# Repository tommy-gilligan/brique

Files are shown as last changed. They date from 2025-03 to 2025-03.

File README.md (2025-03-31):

# RP235x Nokia 3310 Adapter Board

This started as a cute "what if?":

> What if I could type out messages on my smart phone by using tactile buttons like I used to have on my phone back in high school?

Because the board would need to fit into the chassis of a Nokia 3310 and because there are existing doodads that would be sitting alongside the board anyways, scope has crept to include connecting to these other thingamajigs.

3D render of front of adapter board
3D render of back of adapter board

## Setting up web environment

## Setting up rp environment

## Setting up board
### Ordering Board
### Disassemble 3310
### Install Hardware Test Program
### Reassemble 3310
### Manual Test
### Install Custom Software

- RTC
- supercapacitor

### TODO
#### Sooner
##### Hardware
- dress up repo
- Come up with better name
- add back supercap rtc
- double check power regulation
- add jlcpcb part numbers, 3d models

##### Software
- create example that plays RTTTL (and writes it to screen)
- Snake
- USB text entry
- use text_input for inputing secret for TOTP (drives the need for inputting numeric digits easily and RTC)

#### Later
- optional pico-w for wifi/bluetooth (using a module avoids need for recertification?)
    - looks like RP will release such a module (RM2) so go ahead with designing with that in mind
- detect battery type to refuse NiMH
- battery gauge
- flex pcb for keypad?
- LTE modem?
- e-ink display?
- power button used for BOOT/RUN?

https://serdisplib.sourceforge.net/ser/pcd8544.html

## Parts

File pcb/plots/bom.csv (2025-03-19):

Comment | Designator | Footprint | JLCPCB Part #
SW_Push | SW1 | power switch | C128539
10u | C23,C25,C19 | C_0805_2012Metric | C17024
ABM8-272-T3 | Y1 | Crystal_SMD_3225-4Pin_3.2x2.5mm | C20625731
27 | R7,R8 | R_0402_1005Metric | C25100
1k | R2 | R_0402_1005Metric | C25543
1K | R41 | R_0402_1005Metric | C25543
NCP1117-3.3_SOT223 | U2 | SOT-223-3_TabPin2 | C26537
D | D1 | D_0402_1005Metric | C2837790
RV-3028-C7_32.768kHz_1ppm_TA_QC | Y2 | MicroCrystal_RV3028C7 | C3019759
4.7u | C9,C6,C7,C10 | C_0402_1005Metric | C368809
BC847 | Q2,Q7,Q5,Q1,Q9 | SOT-23 | C391423
3.3u | L1 | L_pol_2016 | C42411119
RP2350_80QFN | U5 | RP2350-QFN-80-1EP_10x10_P0.4mm_EP3.4x3.4mm_ThermalVias | C42415655
10k | R35,R34,R38,R1,R36 | R_0402_1005Metric | C60490
100k | R39 | R_0402_1005Metric | C60491
100n | C12,C18,C11,C16,C5,C14,C2,C21,C17,C24,C13,C20,C15,C8 | C_0402_1005Metric | C77020
33 | R3 | R_0402_1005Metric | C852729
15p | C4,C3 | C_0402_1005Metric | C86285
W25Q128JVS | U1 | SOIC-8_5.23x5.23mm_P1.27mm | C97521
4.7uH | L2 | L_Neosid_MicroCoil_Ms36-L | C48427
LED | D2,D3,D4,D7,D9,D5,D6,D8 | LED_REVERSE | C3646932
100nF | C26,C29 | C_0805_2012Metric | C1711
3k | R14,R44,R54,R52,R45,R58,R51,R46,R50,R53,R47,R56,R57,R55,R59,R49,R48 | R_0402_1005Metric | C137872
22uF | C27,C30,C35,C1,C28 | C_0805_2012Metric | C602037
MAX16054 | U4 | SOT-23-6 | C79401
220 | R10,R9,R4,R6,R5,R13,R11,R12 | R_0402_1005Metric | C137872
SW_Push | SW2 | SW_SPST_PTS810 | C221895
100nF | C79 | C_0402_1005Metric | C77020
USB_B_Micro | J5 | USB_Micro-B_Molex_47346-0001 | C132560
120R | R37 | R_0402_1005Metric | C114758
SS34 | D12 | D_SMA | C8678
TP5400 | U3 | SOIC-8_3.9x4.9mm_P1.27mm | C2891434

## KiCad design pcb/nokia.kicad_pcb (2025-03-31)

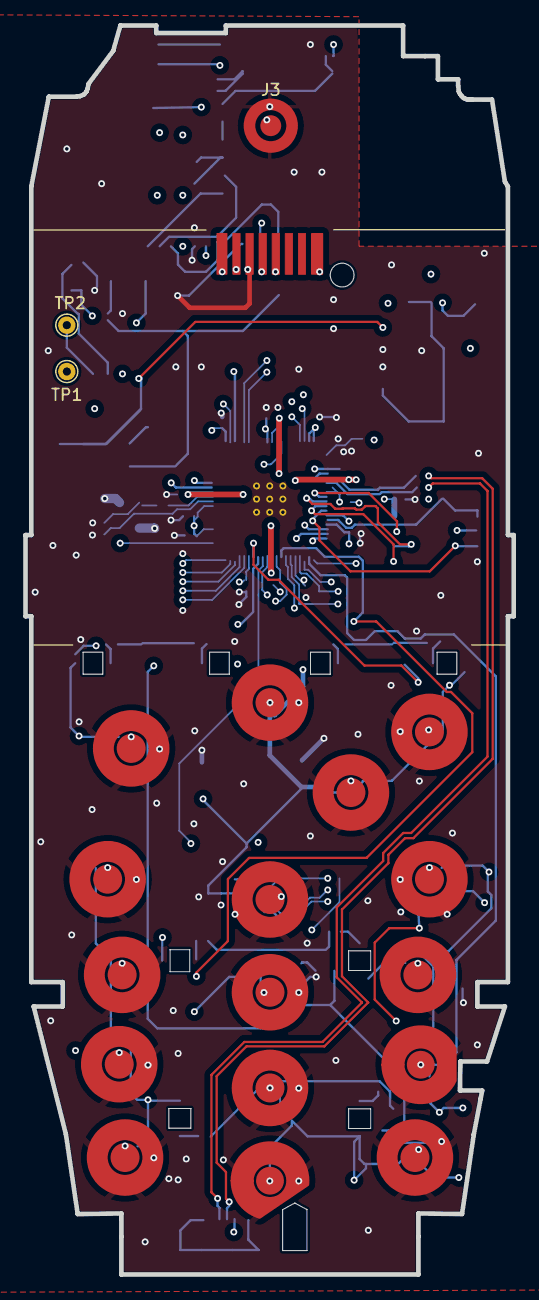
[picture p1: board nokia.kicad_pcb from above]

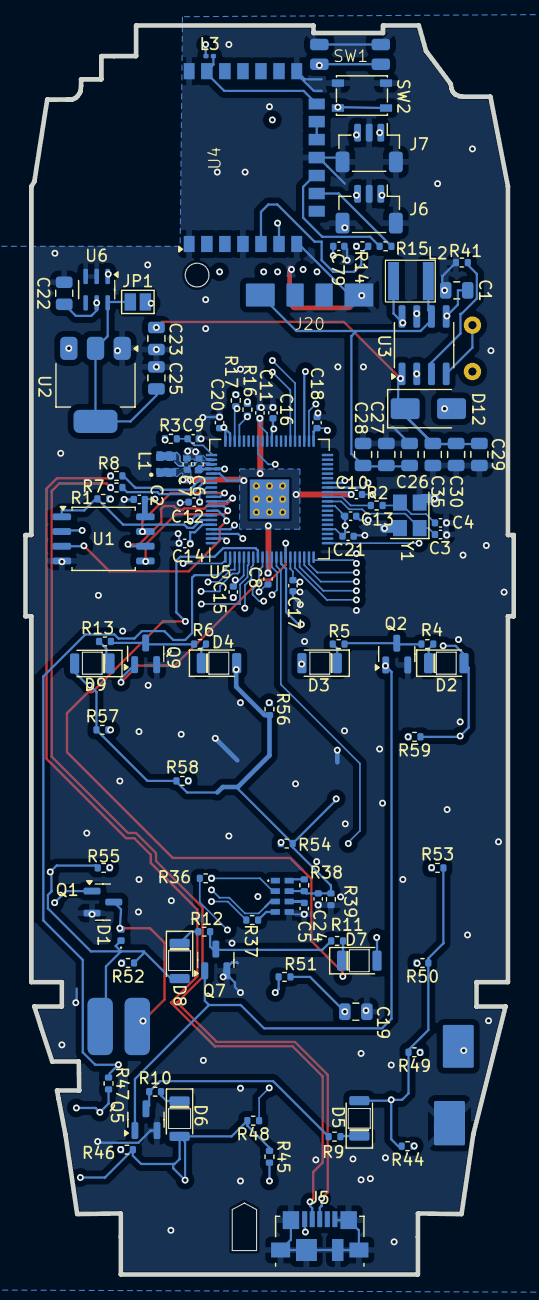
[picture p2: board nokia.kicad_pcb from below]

Board: 4 copper layers, 42.1 x 107.7 mm, 125 parts (105 on the bottom side), 81 nets.

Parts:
C1, C27, C28, C30, C35: 22uF; C_0805_2012Metric
C2, C5, C8, C11, C12, C13, C14, C15, C16, C17, C18, C20, C21, C24: 100n; C_0402_1005Metric
C3, C4: 15p; C_0402_1005Metric
C6, C7, C9, C10: 4.7u; C_0402_1005Metric
C19, C22, C23, C25: 10u; C_0805_2012Metric
C26, C29: 100nF; C_0805_2012Metric
C79: 100nF; C_0402_1005Metric
D1: D; D_0402_1005Metric
D2, D3, D4, D5, D6, D7, D8, D9: LED; LED_REVERSE
D12: SS34; D_SMA
J1: Conn_01x07; screen
J3: Conn_01x02_Pin; PinHeader_1x02_P1.00mm_Vertical_SMD_Pin1Left
J5: USB_B_Micro; USB_Micro-B_Molex_47346-0001
J6, J7: SM03B-SRSS-TB; JST_SH_BM03B-SRSS-TB_1x03-1MP_P1.00mm_Vertical
J20: Battery Connection Pads; battery
JP1: Jumper_2_Open; SolderJumper-2_P1.3mm_Open_Pad1.0x1.5mm
KP0, KP1, KP2, KP4, KP5, KP6, KP7, KP8, KP9: Jumper_2_Open; thick-pad
KP3: 3; thick-pad
KP#1: Jumper_2_Open; thick-pad
KP*1: Jumper_2_Open; thick-pad
KPC1: C; thick-pad
KPDOWN1: Jumper_2_Open; thick-pad
KPSELECT1: Jumper_2_Open; thick-pad
KPUP1: Jumper_2_Open; thick-pad
L1: 3.3u; L_pol_2016
L2: 4.7uH; L_Neosid_MicroCoil_Ms36-L
L3: BLM18EG471SN1D; L_0201_0603Metric
LS2: Buzzer; buzzer
M1: Vibration; vibrator
Q1, Q2, Q5, Q7, Q9: BC847; SOT-23
R1, R15, R16, R17, R36, R38: 10k; R_0402_1005Metric
R2: 1k; R_0402_1005Metric
R3: 33; R_0402_1005Metric
R4, R5, R6, R9, R10, R11, R12, R13: 220; R_0402_1005Metric
R7, R8: 27; R_0402_1005Metric
R14: 470; R_0402_1005Metric
R37: 120R; R_0402_1005Metric
R39: 100k; R_0402_1005Metric
R41: 1K; R_0402_1005Metric
R44, R45, R46, R47, R48, R49, R50, R51, R52, R53, R54, R55, R56, R57, R58, R59: 3k; R_0402_1005Metric
SW1: SW_Push; power switch
SW2: SW_Push; SW_SPST_PTS810
TP1, TP2: TestPoint; TestPoint_THTPad_D1.5mm_Drill0.7mm
U1: W25Q128JVS; SOIC-8_5.23x5.23mm_P1.27mm
U2: NCP1117-3.3_SOT223; SOT-223-3_TabPin2
U3: TP5400; SOIC-8_3.9x4.9mm_P1.27mm
U4: RM2
U5: RP2350_80QFN; RP2350-QFN-80-1EP_10x10_P0.4mm_EP3.4x3.4mm_ThermalVias
U6: MAX16054; SOT-23-6
Y1: ABM8-272-T3; Crystal_SMD_3225-4Pin_3.2x2.5mm
Y2: RV-3028-C7_32.768kHz_1ppm_TA_QC; MicroCrystal_RV3028C7

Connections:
+1V1: C7.1, C8.1, C10.1, C11.1, L1.1, U5.10 (DVDD), U5.32 (DVDD), U5.51 (DVDD), U5.65 (VREG_FB)
+3V3: C2.1, C6.1, C12.1, C13.1, C14.1, C15.1, C16.1, C17.1, C18.1, C19.1, C20.1, C21.1, C22.1, C24.1, D1.1 (K), D2.2 (A), D3.2 (A), D4.2 (A), D5.2 (A), D6.2 (A), D7.2 (A), D8.2 (A), D9.2 (A), J1.1, JP1.2 (B), L3.1, M1.1 (+), R3.1, R16.2, R17.1, R36.1, R38.1, R39.1, R44.2, R45.2, R46.2, R47.2, R48.2, R49.2, R50.1, R51.1, R52.1, R53.2, R54.2, R55.1, R56.2, R57.1, R58.1, R59.1, U1.8 (VCC), U5.5 (IOVDD), U5.15 (IOVDD), U5.24 (IOVDD), U5.29 (IOVDD), U5.41 (IOVDD), U5.50 (IOVDD), U5.59 (ADC_AVDD), U5.60 (IOVDD), U5.64 (VREG_VIN), U5.68 (USB_OTP_VDD), U5.69 (QSPI_IOVDD), U5.76 (IOVDD), U6.5 (OUT), Y2.7 (VDD)
+5V: C23.1, C29.2, C30.2, C35.2, D12.1 (K), U2.3 (VI), U3.1 (VOUT)
+BATT: C26.1, C27.1, C28.1, J20.1, L2.2, U3.6 (BAT)
-BATT: C1.2, C2.2, C3.2, C4.2, C5.2, C6.2, C7.2, C8.2, C9.2, C10.2, C11.2, C12.2, C13.2, C14.2, C15.2, C16.2, C17.2, C18.2, C19.2, C20.2, C21.2, C22.2, C23.2, C24.2, C25.2, C26.2, C27.2, C28.2, C29.1, C30.1, C35.1, C79.1, J1.6, J3.2, J5.5 (GND), J5.6 (Shield), J6.2, J6.MP (MountPin), J7.2, J7.MP (MountPin), J20.4, KP0.1 (A), KP1.1 (A), KP2.1 (A), KP3.1 (A), KP4.1 (A), KP5.1 (A), KP6.1 (A), KP7.1 (A), KP8.1 (A), KP9.1 (A), KP#1.1 (A), KP*1.1 (A), KPC1.1 (A), KPDOWN1.1 (A), KPSELECT1.1 (A), KPUP1.1 (A), LS2.2, Q1.2 (E), Q2.2 (E), Q5.2 (E), Q7.2 (E), Q9.2 (E), R39.2, R41.1, SW1.1, SW2.1, U1.4 (GND), U2.1 (GND), U3.7 (GND), U4.A1 (A1_GND), U4.A4 (A4_GND), U4.A7 (A7_GND), U4.B4 (B4_GND), U4.C1 (C1_GND), U4.C7 (C7_GND), U5.62 (VREG_PGND), U5.81 (GND), U6.2 (GND), U6.3 (CLEAR), Y1.2, Y1.4, Y2.5 (VSS)
/VREG_AVDD: C9.1, R3.2, U5.61 (VREG_AVDD)
/VREG_LX: L1.2, U5.63 (VREG_LX)
EVI: R38.2, Y2.8 (EVI)
GPIO0: J7.3, U5.77 (GPIO0)
GPIO1: J7.1, U5.78 (GPIO1)
GPIO2: Q1.1 (B), U5.79 (GPIO2)
GPIO4: KP#1.2 (B), R46.1, U5.1 (GPIO4)
GPIO5: KP9.2 (B), R47.1, U5.2 (GPIO5)
GPIO6: KP6.2 (B), R52.2, U5.3 (GPIO6)
GPIO7: KP3.2 (B), R55.2, U5.4 (GPIO7)
GPIO8: KPDOWN1.2 (B), R58.2, U5.6 (GPIO8)
GPIO9: KPUP1.2 (B), R57.2, U5.7 (GPIO9)
GPIO10: KP0.2 (B), R45.1, U5.8 (GPIO10)
GPIO11: KP8.2 (B), R48.1, U5.9 (GPIO11)
GPIO12: KPSELECT1.2 (B), R56.1, U5.11 (GPIO12)
GPIO13: KP2.2 (B), R54.1, U5.12 (GPIO13)
GPIO14: KP5.2 (B), R51.2, U5.13 (GPIO14)
GPIO15: Q2.1 (B), Q5.1 (B), Q7.1 (B), Q9.1 (B), U5.14 (GPIO15)
GPIO16: KPC1.2 (B), R59.2, U5.16 (GPIO16)
GPIO17: KP1.2 (B), R53.1, U5.17 (GPIO17)
GPIO18: KP4.2 (B), R50.2, U5.18 (GPIO18)
GPIO19: KP7.2 (B), R49.1, U5.19 (GPIO19)
GPIO20: KP*1.2 (B), R44.1, U5.20 (GPIO20)
GPIO21: LS2.1, U5.21 (GPIO21)
GPIO33: J1.8, U5.42 (GPIO33)
GPIO34: J3.1, U5.43 (GPIO34)
GPIO36: J1.4, U5.45 (GPIO36)
GPIO37: J1.5, U5.46 (GPIO37)
unnamed: C4.1, R2.2, Y1.3
unnamed: D1.2 (A), M1.2 (-), Q1.3 (C)
unnamed: D2.1 (K), R4.2
unnamed: D3.1 (K), R5.2
unnamed: D4.1 (K), R6.2
unnamed: D5.1 (K), R9.2
unnamed: D6.1 (K), R10.2
unnamed: D7.1 (K), R11.2
unnamed: D8.1 (K), R12.2
unnamed: D9.1 (K), R13.2
unnamed: D12.2 (A), L2.1, U3.8 (LX)
unnamed: C79.2, J1.7
unnamed: C25.1, JP1.1 (A), U2.2 (VO), U6.6 (V_{CC})
unnamed: Q2.3 (C), R4.1, R5.1
unnamed: Q5.3 (C), R9.1, R10.1
unnamed: Q7.3 (C), R11.1, R12.1
unnamed: Q9.3 (C), R6.1, R13.1
unnamed: R1.2, SW2.2
unnamed: TP1.1, U3.2 (CHRG)
unnamed: R41.2, U3.3 (PROG)
unnamed: TP2.1, U3.4 (STDBY)
unnamed: R14.1, U4.A6 (A6_DO)
unnamed: R15.1, U4.B3 (B3_IRQ)
unnamed: L3.2, U4.B7 (B7_VDDIO), U4.C2 (C2_VDDBAT)
unnamed: R8.2, U5.66 (USB_DM)
unnamed: R7.2, U5.67 (USB_DP)
unnamed: SW1.2, U6.1 (IN)
unnamed: R37.1, Y2.4 (SDA)
unnamed: C5.1, Y2.6 (VBACKUP)
QSPI_SCLK: U1.6 (CLK), U5.71 (QSPI_SCLK)
QSPI_SD0: U1.5 (DI(IO0)), U5.72 (QSPI_SD0)
QSPI_SD1: U1.2 (DO(IO1)), U5.74 (QSPI_SD1)
QSPI_SD2: U1.3 (IO2), U5.73 (QSPI_SD2)
QSPI_SD3: U1.7 (IO3), U5.70 (QSPI_SD3)
QSPI_SS: R1.1, U1.1 (~CS), U5.75 (QSPI_SS)
RM2_CS: R15.2, U4.B2 (B2_CS)
RM2_DIO: R14.2, U4.A5 (A5_DI)
RM2_POWER: U4.B5 (B5_WLON), U4.B6 (B6_BTON)
RTC_SCL: R17.2, U5.58 (GPIO47_ADC7), Y2.3 (SCL)
RTC_SDA: R16.1, R37.2, U5.57 (GPIO46_ADC6)
SWCLK: J6.1, U5.33 (SWCLK)
SWD: J6.3, U5.34 (SWD)
USB_D+: J5.3 (D+), R7.1
USB_D-: J5.2 (D-), R8.1
VBUS: C1.1, J5.1 (VBUS), U3.5 (VCC)
XIN: C3.1, U5.30 (XIN), Y1.1
XOUT: R2.1, U5.31 (XOUT)
~INT: R36.2, U5.53 (GPIO42_ADC2), Y2.2 (~INT)

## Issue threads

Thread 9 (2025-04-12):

Institute changelog and force branched flow for issues

tommy-gilligan, 2025-04-12:

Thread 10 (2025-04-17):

Improve battery monitoring

tommy-gilligan, 2025-04-17:
- Add battery gauge
- Detect NiMH/LiPo to prevent using NiMH.  Could use ADC
- Use charge/standby pins from charging IC

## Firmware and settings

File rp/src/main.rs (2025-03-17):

#![no_std]
#![no_main]

#[unsafe(link_section = ".start_block")]
#[used]
pub static IMAGE_DEF: ImageDef = ImageDef::secure_exe();

// Program metadata for `picotool info`.
// This isn't needed, but it's recomended to have these minimal entries.
#[unsafe(link_section = ".bi_entries")]
#[used]
pub static PICOTOOL_ENTRIES: [embassy_rp::binary_info::EntryAddr; 6] = [
    embassy_rp::binary_info::rp_program_name!(c"rp235x-nokia-3310"),
    // in repo root: find pcb -type f \( -exec sha1sum "$PWD"/{} \; \) | awk '{print $1}' | sort | sha1sum | cut -b-10
    embassy_rp::binary_info::rp_pico_board!(c"rp235x-nokia-3310-5da11fc30e"),
    embassy_rp::binary_info::rp_program_description!(
        c"This example tests the RP Pico on board LED, connected to gpio 25"
    ),
    embassy_rp::binary_info::rp_cargo_version!(),
    embassy_rp::binary_info::rp_program_build_attribute!(),
    embassy_rp::binary_info::rp_program_url!(
        c"https://github.com/tommy-gilligan/rp235x-nokia-3310"
    ),
];

mod rtc;
mod button;
mod device;
mod usb;

use assign_resources::assign_resources;
use core::cell::RefCell;
use defmt::unwrap;
use defmt_rtt as _;
use embassy_executor::{Executor, Spawner};
use embassy_rp::{
    bind_interrupts,
    block::ImageDef,
    multicore::{Stack, spawn_core1},
    peripherals,
    peripherals::USB,
    spi,
    spi::Spi,
    usb::InterruptHandler,
};
use embassy_sync::blocking_mutex::Mutex;
use panic_probe as _;
use static_cell::StaticCell;

assign_resources! {
    usbs: Usbs{
        usb: USB,
    }
}

bind_interrupts!(struct Irqs {
    USBCTRL_IRQ => InterruptHandler<USB>;
});

static mut CORE1_STACK: Stack<4096> = Stack::new();
static EXECUTOR1: StaticCell<Executor> = StaticCell::new();

#[embassy_executor::main]
async fn main(_spawner: Spawner) {
    let p = embassy_rp::init(Default::default());
    let r = split_resources!(p);
    spawn_core1(
        p.CORE1,
        unsafe { &mut *core::ptr::addr_of_mut!(CORE1_STACK) },
        move || {
            let executor1 = EXECUTOR1.init(Executor::new());
            executor1.run(|spawner| unwrap!(spawner.spawn(usb::big_usb_task(spawner, r.usbs))));
        },
    );
    let _clock = rtc::Clock::new(p.I2C1, p.PIN_46, p.PIN_47);

    let mut display_config = spi::Config::default();
    display_config.frequency = 4_000_000;

    main_menu::main_menu(
        device::Device::new(
            p.PIN_2,
            p.PIN_4,
            p.PIN_5,
            p.PIN_6,
            p.PIN_7,
            p.PIN_8,
            p.PIN_9,
            p.PIN_10,
            p.PIN_11,
            p.PIN_12,
            p.PIN_13,
            p.PIN_14,
            p.PIN_15,
            p.PIN_16,
            p.PIN_17,
            p.PIN_18,
            p.PIN_19,
            p.PIN_20,
            p.PIN_21,
            p.PIN_33,
            p.PIN_36,
            p.PIN_37,
            p.PWM_SLICE2,
            &Mutex::new(
                RefCell::new(
                    Spi::new_blocking(
                        p.SPI0,
                        p.PIN_38,
                        p.PIN_39,
                        p.PIN_32,
                        display_config,
                    )
                )
            ),
        ).unwrap(),
        button::Button::new(p.PIN_28),
        crate::device::CdcSend,
        crate::device::Handler
    ).await;
}

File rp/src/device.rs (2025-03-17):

use core::cell::RefCell;
use embassy_rp::pwm::PwmError;
use embassy_rp::peripherals::{
    PIN_2, PIN_4, PIN_5, PIN_6, PIN_7, PIN_8, PIN_9, PIN_10, PIN_11, PIN_12, PIN_13, PIN_14,
    PIN_15, PIN_16, PIN_17, PIN_18, PIN_19, PIN_20, PIN_21, PIN_33, PIN_36, PIN_37, PWM_SLICE2,
    SPI0,
};
use embassy_sync::blocking_mutex::raw::NoopRawMutex;
use embedded_graphics_core::{
    Pixel,
    pixelcolor::BinaryColor,
    prelude::{Dimensions, DrawTarget},
    primitives::Rectangle,
};
mod backlight;
mod buzzer;
mod display;
mod keypad;
mod vibration_motor;

pub struct Device<'a> {
    keypad: keypad::ContactKeypad<'a>,
    backlight: backlight::Light<'a>,
    vibration_motor: vibration_motor::Motor<'a>,
    buzzer: buzzer::Beeper<'a>,
    display: display::Display<'a>,
}

unsafe impl Send for Device<'_> {}

impl<'a> Device<'a> {
    #[allow(clippy::too_many_arguments)]
    pub fn new(
        pin_2: PIN_2,
        pin_4: PIN_4,
        pin_5: PIN_5,
        pin_6: PIN_6,
        pin_7: PIN_7,
        pin_8: PIN_8,
        pin_9: PIN_9,
        pin_10: PIN_10,
        pin_11: PIN_11,
        pin_12: PIN_12,
        pin_13: PIN_13,
        pin_14: PIN_14,
        pin_15: PIN_15,
        pin_16: PIN_16,
        pin_17: PIN_17,
        pin_18: PIN_18,
        pin_19: PIN_19,
        pin_20: PIN_20,
        pin_21: PIN_21,
        pin_33: PIN_33,
        pin_36: PIN_36,
        pin_37: PIN_37,
        pwm_slice2: PWM_SLICE2,
        spi_bus: &'a embassy_sync::blocking_mutex::Mutex<
            NoopRawMutex,
            RefCell<embassy_rp::spi::Spi<'a, SPI0, embassy_rp::spi::Blocking>>,
        >,
    ) -> Result<Self, display_interface::DisplayError> {
        Ok(
            Self {
                keypad: keypad::ContactKeypad::new(
                    pin_16, pin_12, pin_9, pin_8, pin_17, pin_13, pin_7, pin_18, pin_14, pin_6, pin_19,
                    pin_11, pin_5, pin_20, pin_10, pin_4,
                ),
                backlight: backlight::Light::new(pin_15),
                vibration_motor: vibration_motor::Motor::new(pin_2),
                buzzer: buzzer::Beeper::new(pwm_slice2, pin_21),
                display: display::Display::new(spi_bus, pin_37, pin_36, pin_33)?,
            }
        )
    }
}

impl shared::Device for Device<'_> {}
use shared::{Backlight, Buzzer, Keypad, Rtc, VibrationMotor};

impl Backlight for Device<'_> {
    fn on(&mut self) {
        self.backlight.on();
    }

    fn off(&mut self) {
        self.backlight.off();
    }
}

impl Buzzer for Device<'_> {
    type Error = PwmError;

    fn mute_buzzer(&mut self) -> Result<(), Self::Error> {
        self.buzzer.mute_buzzer()
    }

    fn unmute_buzzer(&mut self) -> Result<(), Self::Error> {
        self.buzzer.unmute_buzzer()
    }

    fn set_volume(&mut self, volume: u8) {
        self.buzzer.set_volume(volume);
    }

    fn set_frequency(&mut self, frequency: u16) -> Result<(), Self::Error> {
        self.buzzer.set_frequency(frequency)
    }
}

impl VibrationMotor for Device<'_> {
    fn start_vibrating(&mut self) {
        self.vibration_motor.start_vibrating();
    }

    fn stop_vibrating(&mut self) {
        self.vibration_motor.stop_vibrating();
    }
}

impl Keypad for Device<'_> {
    async fn event(&mut self) -> shared::KeyEvent {
        self.keypad.event().await
    }
}

impl DrawTarget for Device<'_> {
    type Color = BinaryColor;

    type Error = ();

    fn draw_iter<I: IntoIterator<Item = Pixel<<Self as DrawTarget>::Color>>>(
        &mut self,
        i: I,
    ) -> Result<(), <Self as DrawTarget>::Error> {
        let _ = self.display.draw_iter(i);
        Ok(())
    }
}

impl Dimensions for Device<'_> {
    fn bounding_box(&self) -> Rectangle {
        self.display.bounding_box()
    }
}

pub struct Handler;

impl shared::SystemRequestHandler for Handler {
    async fn handle_request(&mut self, _request: shared::SystemRequest) {}
}

pub struct CdcSend;

impl shared::SystemResponse for CdcSend {
    fn take(&mut self) -> Option<[u8; 64]> {
        None
    }
}

impl Rtc for Device<'_> {
    type Error = ();

    fn timestamp(&mut self) -> Result<i64, ()> {
        Ok(0)
    }
}

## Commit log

2025-03-03 add reset to boot
    [main.rs]
2025-03-13 add button up
2025-03-19 pcb v0.3
    [bom.csv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]
